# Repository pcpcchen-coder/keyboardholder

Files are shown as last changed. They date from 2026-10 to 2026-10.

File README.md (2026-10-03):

# Keyboard Holder — v0.5.0 試作版

可拆式螢幕前方鍵盤收納架。收納時才掛上，鍵盤長邊水平、按鍵朝外、後傾 12°。以 AOPEN 27HC5R 與 Keychron V6 Max（V6M-D3）為原始尺寸參考，使用 PLA 列印。

**本版將三段調整改到上下掛框的卡榫接合處，改變整支掛架總長度，對應不含底座的螢幕機身高度 335／355／375 mm。** 托槽、下掛框及下框止擋改為一體列印，調整時整個下半部一起移動。

尚未實際列印、試掛或完成 PLA 長期承重、卡榫疲勞與螢幕機殼受力測試，沒有承重額定值。先印試配件，再印正式零件。

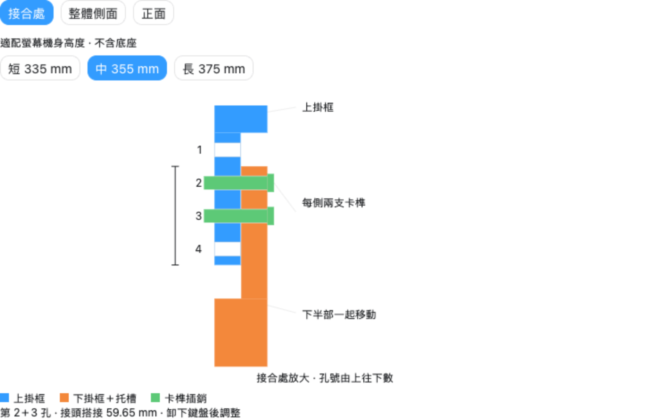
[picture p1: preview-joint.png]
三段可變長度接合處


## 三段怎麼調整

上掛框的搭接片有四個孔，由上往下數為 1–4；下掛框有兩個孔。每側插入兩支相同的卡榫插銷，定位孔距 20 mm。

| 段位 | 對應螢幕機身高度 | 上掛框選孔 | 接頭搭接長度 | 掛架外部總高 |
| --- | ---: | --- | ---: | ---: |
| 短 | 335 mm | 第 1＋2 孔 | 79.65 mm | 347 mm |
| 中 | 355 mm | 第 2＋3 孔 | 59.65 mm | 367 mm |
| 長 | 375 mm | 第 3＋4 孔 | 39.65 mm | 387 mm |

「機身高度」從螢幕頂部量到機身底部；「掛架外部總高」另含上方 10 mm 掛鉤壁及預留 2 mm 軟墊。三段共用同一組列印零件。

換段前先取下鍵盤與掛架，平放桌面、托住兩半掛框，壓合叉端並抽出該側兩支插銷，再移動下掛框對孔。左右必須選同一段，每側兩支插銷都要完全穿出並回彈。拆銷後兩半可以分離，不能在承重時換段。

## 適配範圍

本次確認的螢幕量測是：機身高 **355 mm**、左右約距中心 21 cm 處上緣厚 **10 mm**、下方實體框高 **15 mm**。335 與 375 mm 是另外兩段的設計目標，尚未對應實測的其他螢幕。

其他螢幕也須確認上緣厚度、後蓋輪廓、曲率與下框接觸位置。現有掛鉤以 10 mm 厚與 1500R 曲面為起點；高度相符不能單獨保證掛鉤適配。SCAD 可修改這些參數，修改後要重新匯出、試配。

鍵盤尺寸採官方寬 447.9 × 深 149 mm，組裝重量 1110 ± 10 g。使用者曾粗量厚度 30 mm，但未確定含鍵帽的最大厚度，所以以 45 mm 包絡檢查，托槽硬壁間內寬保留 **61 mm**，再用軟墊調整。

後傾 **12°**、前擋高 **24 mm**、靠背高 **115 mm**。托底內側後緣固定在機身底部上方 55 mm；下框止擋固定在機身底部上方 3–12 mm。左右掛臂中心距 **425.9 mm**，托槽寬度方向的承托寬為每側 32 mm。

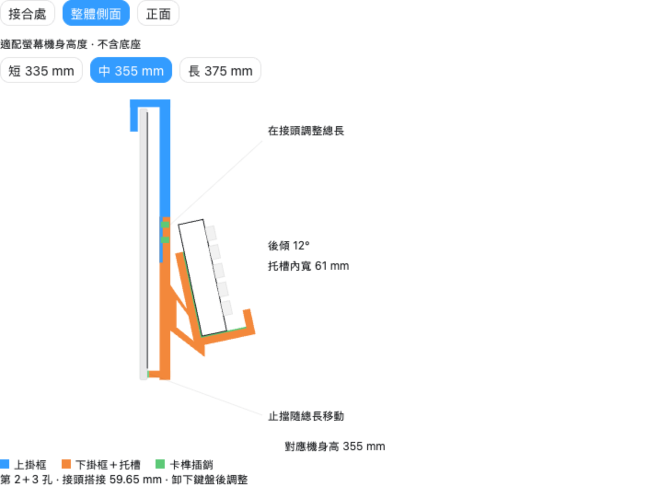
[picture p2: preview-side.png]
355 mm 中段的側面示意


## 檔案與列印數量

- [可修改的 OpenSCAD 設計](keyboard-front-hanger-v05.scad)
- [STL 列印檔](STL/)
- [列印與組裝說明](列印與組裝說明.txt)
- [STL 幾何檢查](validation/mesh-validation.json)、[三段交疊檢查](validation/geometry-checks.json)
- [三段共用零件檢查](validation/stage-invariance.json)、[STL 檢查程式](validation/check_stl.py)

| 檔案 | 數量 | 用途 |
| --- | ---: | --- |
| `upper_left.stl`、`upper_right.stl` | 各 1 | 上掛框，含四孔搭接片 |
| `lower_left.stl`、`lower_right.stl` | 各 1 | 下掛框、托槽、下框止擋一體件 |
| `pin_joint.stl` | 4 | 每側兩支定位插銷；可另印備品 |
| `coupon_joint.stl` | 試配 1 | 插銷孔尺寸試片 |
| `joint_upper_coupon.stl`、`joint_lower_coupon.stl` | 試配各 1 | 完整搭接處三段試片，搭配兩支插銷 |
| `top_fit_left.stl`、`top_fit_right.stl` | 試配各 1 | 左右曲面掛鉤試片，僅試尺寸，不承重 |

正式組裝共 **8 件**，不需要金屬螺絲。請使用 v0.5 整套掛框；v0.4 的獨立滑動托槽與下掛框不適用本版。v0.4 保留在 [Git 歷史](https://github.com/pcpcchen-coder/keyboardholder/tree/36507df45e73854c823199b77524b0c7c6231bcc)。

## 列印與安裝

建議起始設定：PLA、0.4 mm 噴嘴、0.2 mm 層高、6 道外牆、6 層頂底；主件 50% 填充，插銷 100% 填充。保持 STL 原有方向、100% 比例，以 mm 匯入。插銷平躺列印，使叉臂在列印平面內彎曲。

最長零件 213.5 mm。名義 220 × 220 mm 平台可能容納，但長邊每側僅約 3.25 mm 餘量；必須檢查有效範圍、裙邊、夾具與切片結果，不能用縮放來塞入。若平台或翹曲控制需要更多邊緣空間，應重新分件。

孔洞與靠背開窗仍可能需要橋接或局部支撐，依切片預覽與機器能力處理。確認支撐能拆除，不要留下堵孔或卡住倒鉤的殘料。

在掛鉤上緣／後蓋接觸處、下框止擋、托底及靠背貼約 2 mm 軟墊，再依試配補足托槽間隙。軟墊貼在支架上，勿以壓鍵帽定位。先離開螢幕測試配合與替代負載，再空掛確認所有受力點落在實體外框、面板保持空隙、螢幕底座不前傾，最後扶住鍵盤緩慢放入。

## 檢查紀錄與限制

- OpenSCAD 2026.10.02 匯出 10 種二進位 STL，全部通過封閉性、面方向一致、單一連通實體、非退化三角形、正體積與列印原點檢查。
- 三段都檢查了上下掛框、插銷、鍵盤包絡與理想曲面螢幕；沒有正體積交疊。插銷頭在貼合面可有零體積接觸。
- 三段的正式零件幾何相同，只有裝配位置改變；試配件可先驗證孔距與插銷配合。
- 尚未驗證列印公差、軟墊壓縮、承重變形、長期蠕變、插拔壽命或其他機種適配。PLA 卡榫如發白、裂開、鬆動或不能回彈，先卸載並更換。

重新檢查：`python3 validation/check_stl.py`。SCAD 的 `part` 選零件，`stage` 0／1／2 選短／中／長；`assembly` 是組裝預覽，不是整組列印配置。

圖片是結構示意，鍵帽排列、底座與機身外觀未精確建模；加工以 SCAD／STL 為準。

## 尺寸來源

- [Keychron V6 Max 官方規格](https://www.keychron.com/products/keychron-v6-max-qmk-via-wireless-custom-mechanical-keyboard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)：寬、深、重量與未含鍵帽的外殼高度。
- [Acer／AOPEN HC5 系列官方商品頁](https://store.acer.com/en-us/27-aopen-hc5-series-gaming-monitor-27hc5r-pbiipx)：1500R 系列參考；市場後綴不同，不代表後蓋外形完全相同。
- 機身高 355 mm、局部厚 10 mm、實體下框 15 mm 由使用者量測；335／355／375 mm 三段由使用者確認。

版本日期：2026-10-03。

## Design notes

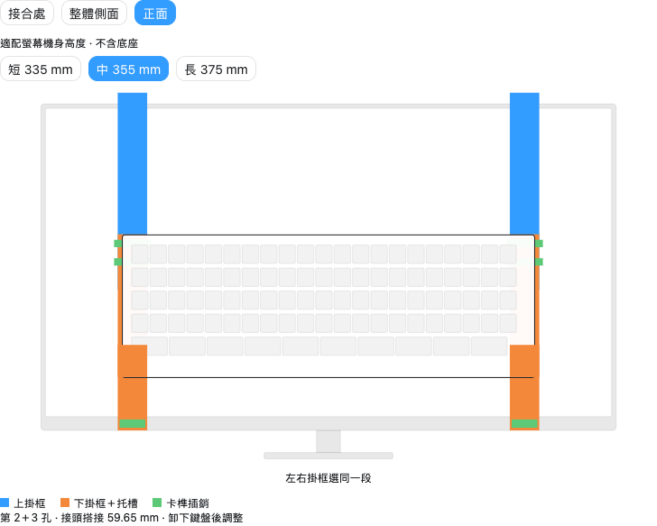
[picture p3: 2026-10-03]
preview-front.png

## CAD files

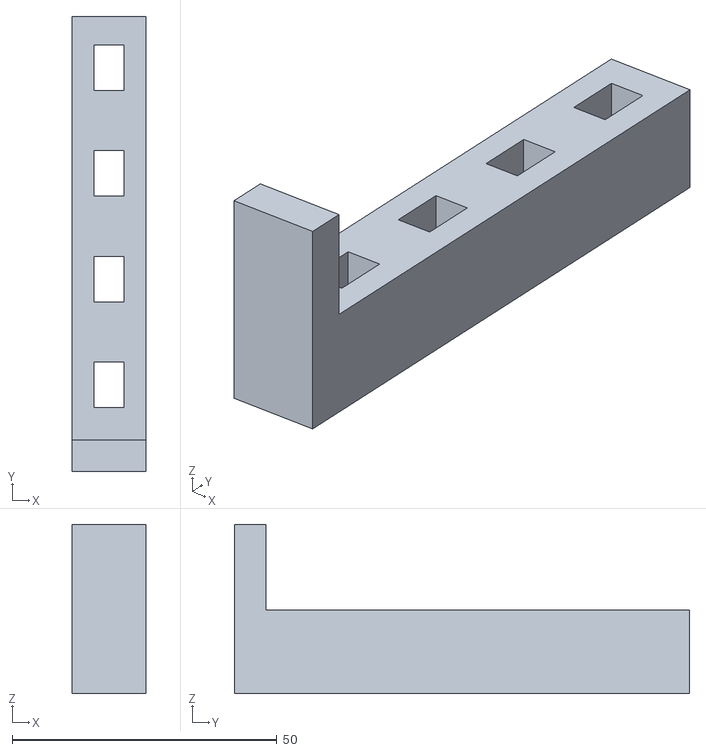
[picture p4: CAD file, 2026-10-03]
STL/joint_upper_coupon.stl
14.0 x 86.0 x 32.0

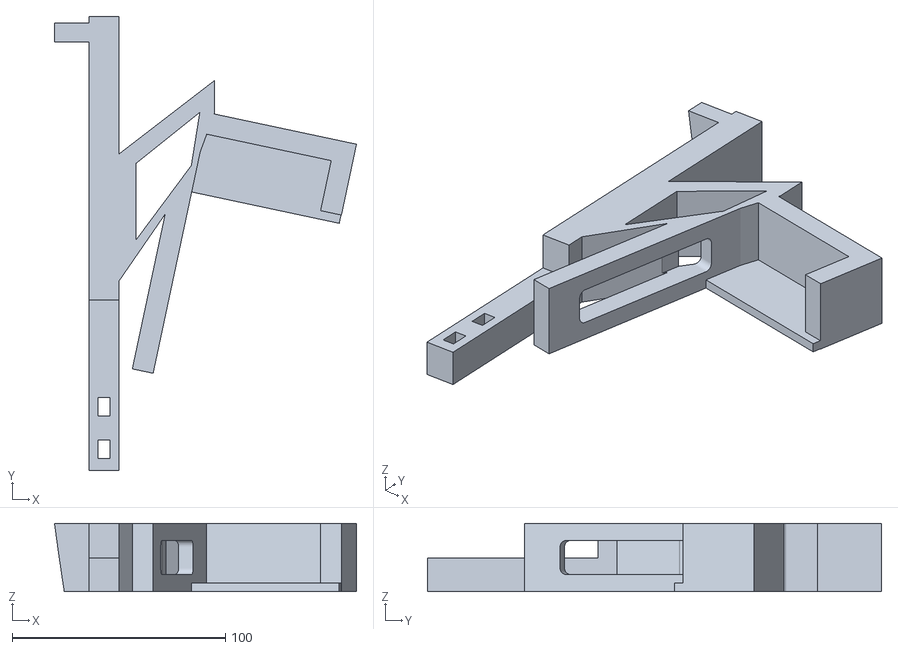
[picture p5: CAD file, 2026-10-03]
STL/lower_left.stl
141.7 x 213.1 x 32.0

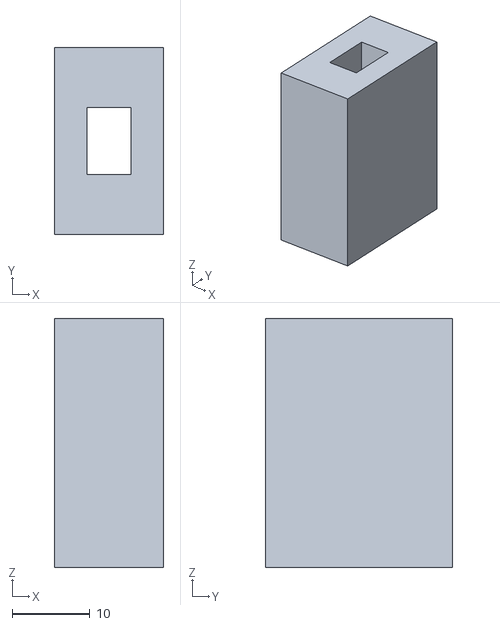
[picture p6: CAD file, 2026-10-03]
STL/coupon_joint.stl
14.0 x 24.0 x 32.0

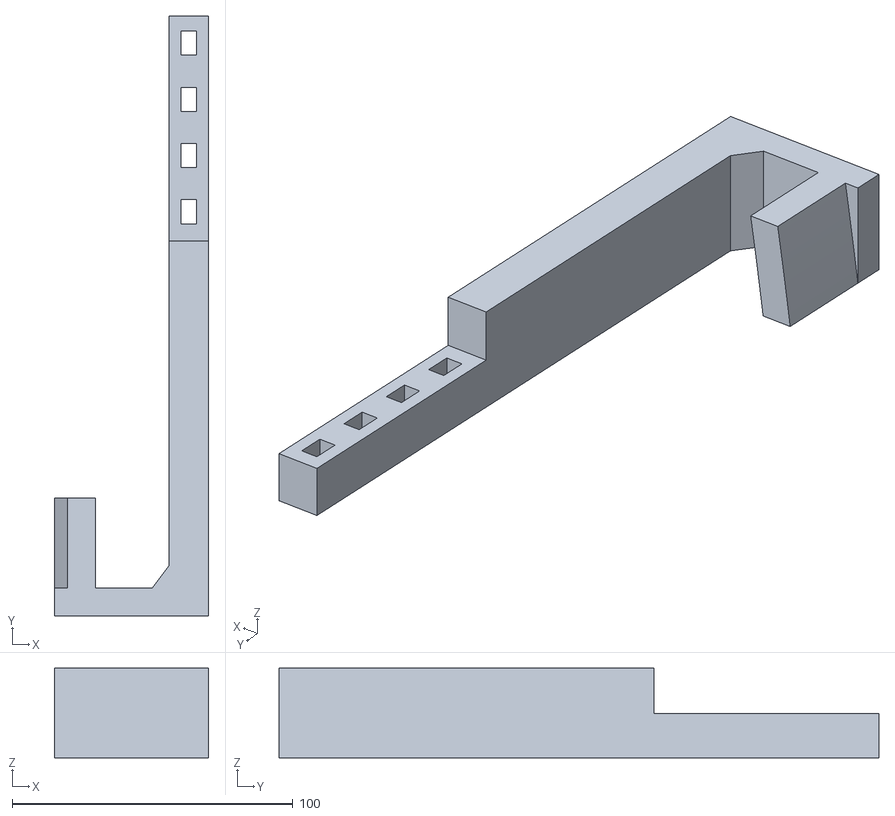
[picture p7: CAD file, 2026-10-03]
STL/upper_right.stl
54.8 x 213.5 x 32.0

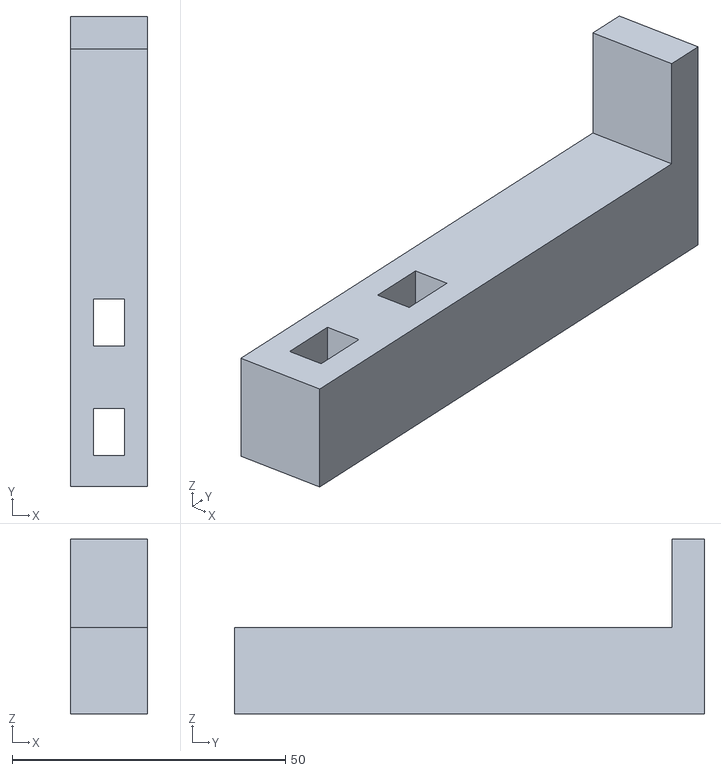
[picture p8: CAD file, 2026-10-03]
STL/joint_lower_coupon.stl
14.0 x 86.0 x 32.0

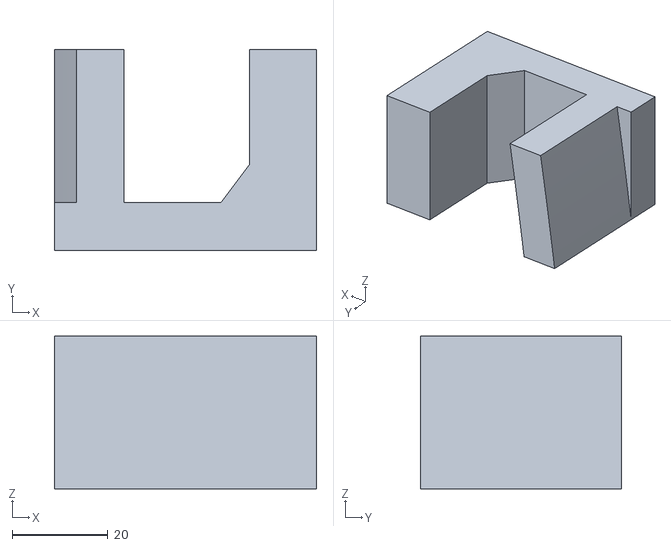
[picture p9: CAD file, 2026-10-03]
STL/top_fit_right.stl
54.8 x 42.0 x 32.0

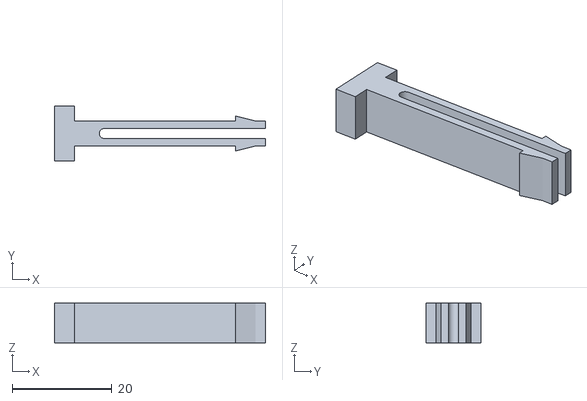
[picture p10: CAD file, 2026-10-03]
STL/pin_joint.stl
42.4 x 11.0 x 8.00

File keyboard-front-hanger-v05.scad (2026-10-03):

/* v0.5.0 — 螢幕前掛式鍵盤收納架，PLA 試作版
   三段調整位於上下掛框的搭接處，對應機身高 335/355/375 mm。
   托槽、下掛框及下框止擋一體列印，隨總長度一起移動。
   每側 2 支可抽換卡榫插銷；所有零件相同，不必為各段另印。
   座標 X 朝使用者，Y 從螢幕頂部往下，Z 沿螢幕寬度。單位 mm。
   尚未實體試配、承重或疲勞測試，沒有承重額定值。
*/
/* [輸出] */
part="assembly"; // [assembly,upper_left,upper_right,lower_left,lower_right,pin_joint,coupon_joint,joint_upper_coupon,joint_lower_coupon,top_fit_left,top_fit_right]
stage=1; // [0:短 335 mm 機身,1:中 355 mm 機身,2:長 375 mm 機身]
show_pins=true;
$fn=48;

/* [螢幕與鍵盤] */
height_positions=[335,355,375];
monitor_top_thickness=10;
bottom_bezel_height=15;
monitor_width=625; // 僅預覽；未確認實機寬度
curve_radius=1500; // 27HC5R 系列參考，後蓋仍須試配
keyboard_width=447.9;
keyboard_depth=149;
keyboard_thickness_envelope=45; // 預留包絡，非實測

/* [後傾托槽] */
recline_angle=12;
slot_width=61; // 硬壁間距，垂直於鍵盤背面量測
tray_floor_wall=10;
tray_back_wall=10;
tray_front_wall=10;
tray_front_height=24;
tray_back_height=115;
tray_side_height=28;
side_stop_wall=4;
keyboard_side_clearance=2;
seat_x=70;
seat_bottom_offset=55; // 托底內側後緣距機身底部

/* [可變長度掛框] */
arm_width=32;
rail_back=16;
rail_thickness=14;
hook_wall=10;
rear_hook_drop=30;
upper_end=201.5;
joint_tongue_length=80;
joint_clearance=0.35;
joint_pin_pitch=20;
joint_first_pin=10;
bezel_margin=3;

/* [可拆卡榫插銷] */
pin_shaft_width=5;
pin_thickness=8;
pin_hole_width=5.6;
pin_hole_height=8.6;
pin_head_width=11;
pin_head_length=4;
pin_split_width=2;
pin_split_root=6;
pin_barb=1;
pin_axial_clearance=0.4;
pin_ramp_length=4;
pin_tip_length=2;

/* [另備軟墊] */
top_pad=2;
rear_pad=2;
front_pad=2;
keyboard_pad=2;
hook_fit_clearance=0.6;

monitor_height=height_positions[stage];
extension=monitor_height-height_positions[0];
rail_front=rail_back+rail_thickness;
pin_x=rail_back+rail_thickness/2;
cup_width=arm_width;
pair_offset=keyboard_width+keyboard_side_clearance+2*side_stop_wall-cup_width;
function sag(u)=curve_radius-sqrt(curve_radius*curve_radius-u*u);
function fc(z)=sag(pair_offset/2+z-arm_width/2)-sag(pair_offset/2);
curve_min=min(fc(0),fc(arm_width));
curve_max=max(fc(0),fc(arm_width));
rear_inner=-monitor_top_thickness-rear_pad-hook_fit_clearance;
x_min=rear_inner-hook_wall+curve_min;
y_min=-top_pad-hook_wall;
upper_shoulder=upper_end-joint_tongue_length;
lower_start=upper_shoulder+joint_clearance; // 下掛框最短段的原點
lower_length=height_positions[0]-lower_start;
half_low=arm_width/2-joint_clearance/2;
half_high=arm_width/2+joint_clearance/2;
seat_local=lower_length-seat_bottom_offset;
seat=monitor_height-seat_bottom_offset;
bumper_local_y=lower_length-bottom_bezel_height+bezel_margin;
bumper_height=bottom_bezel_height-2*bezel_margin;
pin_rows=[for(i=[0:3]) lower_start+joint_first_pin+i*joint_pin_pitch];
active_rows=[lower_start+extension+joint_first_pin,
             lower_start+extension+joint_first_pin+joint_pin_pitch];
overlap=upper_end-(lower_start+extension);
function tx(u,v)=seat_x+u*cos(recline_angle)+v*sin(recline_angle);
function ty(u,v)= -u*sin(recline_angle)+v*cos(recline_angle);

assert(stage>=0 && stage<=2 && floor(stage)==stage,"stage 必須為 0/1/2。");
assert(len(height_positions)==3 && height_positions[1]-height_positions[0]==joint_pin_pitch && height_positions[2]-height_positions[1]==joint_pin_pitch,"三段高度差須與定位孔距相同。");
assert(overlap>=39,"最長段搭接不足。");
assert(bottom_bezel_height>=12,"下框不足，請重新設計接觸點。");
assert(rail_back-curve_max>8,"掛框距面板空隙不足。");
assert(tx(-tray_back_wall,-tray_back_height)>rail_front+4,"後傾靠背與掛框過近。");
assert(tx(keyboard_pad,-keyboard_depth-keyboard_pad)>rail_front+6,"鍵盤包絡與掛框過近。");
assert(seat_local-70>joint_tongue_length+4,"托槽肋條與可調接頭衝突。");
assert(pin_rows[3]+pin_hole_height/2+5<upper_end,"末孔距端部不足。");
assert(pin_shaft_width>pin_split_width+2.4,"卡榫叉臂過薄。");
assert(slot_width>=keyboard_thickness_envelope+2*keyboard_pad+2,"托槽空間不足。");

module rect(x,y,w,h){translate([x,y]) square([w,h]);}
module xz_prism(points,y0,depth){
  translate([0,y0,0]) multmatrix([[1,0,0,0],[0,0,1,0],[0,1,0,0],[0,0,0,1]])
    linear_extrude(height=depth) polygon(points);
}
module curved_strip(a,b,y0,depth){
  xz_prism(concat(
    [for(i=[0:16]) let(z=arm_width*i/16) [fc(z)+a,z]],
    [for(i=[16:-1:0]) let(z=arm_width*i/16) [fc(z)+b,z]]
  ),y0,depth);
}
module mirrored_width(){translate([0,0,arm_width]) mirror([0,0,1]) children();}
module through_slot(y){
  translate([pin_x-pin_hole_width/2,y-pin_hole_height/2,-1])
    cube([pin_hole_width,pin_hole_height,arm_width+2]);
}
module upper(){
  difference(){
    union(){
      linear_extrude(height=arm_width) union(){
        rect(x_min,y_min,rail_front-x_min,hook_wall);
        rect(rail_back,y_min,rail_thickness,upper_shoulder-y_min);
        polygon([[rail_back,-top_pad],[rail_back,6],[rail_back-6,-top_pad]]);
      }
      translate([rail_back,upper_shoulder-0.1,0])
        cube([rail_thickness,joint_tongue_length+0.1,half_low]);
      curved_strip(rear_inner-hook_wall,rear_inner,y_min,rear_hook_drop-y_min);
    }
    for(y=pin_rows) through_slot(y);
  }
}
module lower_rail(){
  difference(){
    union(){
      translate([rail_back,0,half_high]) cube([rail_thickness,joint_tongue_length+0.1,arm_width-half_high]);
      translate([rail_back,joint_tongue_length,0]) cube([rail_thickness,lower_length-joint_tongue_length,arm_width]);
      xz_prism(concat([for(i=[0:16]) let(z=arm_width*i/16) [fc(z)+front_pad,z]],
                     [[rail_front,arm_width],[rail_front,0]]),bumper_local_y,bumper_height);
    }
    for(y=[joint_first_pin,joint_first_pin+joint_pin_pitch]) through_slot(y);
  }
}
module reclined(seat_y){translate([seat_x,seat_y,0]) rotate([0,0,-recline_angle]) children();}
module backrest_window(seat_y){
  reclined(seat_y) hull()
    for(v=[-95,-28]) for(z=[11,cup_width-11])
      translate([-tray_back_wall-1,v,z]) rotate([0,90,0]) cylinder(h=tray_back_wall+2,r=3);
}
module cup(seat_y){
  difference(){
    union(){
      linear_extrude(height=cup_width) union(){
        reclined(seat_y) union(){
          rect(-tray_back_wall,0,slot_width+tray_front_wall+tray_back_wall,tray_floor_wall);
          rect(-tray_back_wall,-tray_back_height,tray_back_wall,tray_back_height+tray_floor_wall);
          rect(slot_width,-tray_front_height,tray_front_wall,tray_front_height+tray_floor_wall);
        }
        polygon([[rail_front-0.5,seat_y-70],[seat_x-6,seat_y-20],
                 [seat_x+5,seat_y+10],[seat_x+5,seat_y+25],[rail_front-0.5,seat_y-10]]);
      }
      translate([0,0,cup_width-side_stop_wall]) linear_extrude(height=side_stop_wall)
        reclined(seat_y) rect(-0.1,-tray_side_height,slot_width+tray_front_wall-0.1,tray_side_height+tray_floor_wall-0.2);
    }
    translate([0,0,-1]) linear_extrude(height=cup_width+2)
      polygon([[38,seat_y-50],[64,seat_y-15],[68,seat_y+10],[38,seat_y-14]]);
    backrest_window(seat_y);
  }
}
module lower(){union(){lower_rail();cup(seat_local);}}
module lower_in_place(){translate([0,lower_start+extension,0]) lower();}
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

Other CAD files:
STL/lower_right.stl
STL/upper_left.stl
STL/top_fit_left.stl

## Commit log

2026-10-03 Initialize v0.4.0 keyboard holder prototype documentation
2026-10-03 Add v0.4.0 printable prototype, snap pins, previews and validation
    [coupon_joint.stl, coupon_rail.stl, coupon_slider.stl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]
2026-10-03 Fix length adjustment at frame joint for 335/355/375 mm monitors (v0.5.0)
    [coupon_joint.stl, coupon_rail.stl, coupon_slider.stl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]
